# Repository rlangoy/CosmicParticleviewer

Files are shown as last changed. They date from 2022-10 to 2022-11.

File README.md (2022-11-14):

# Cosmic particle readout system overview
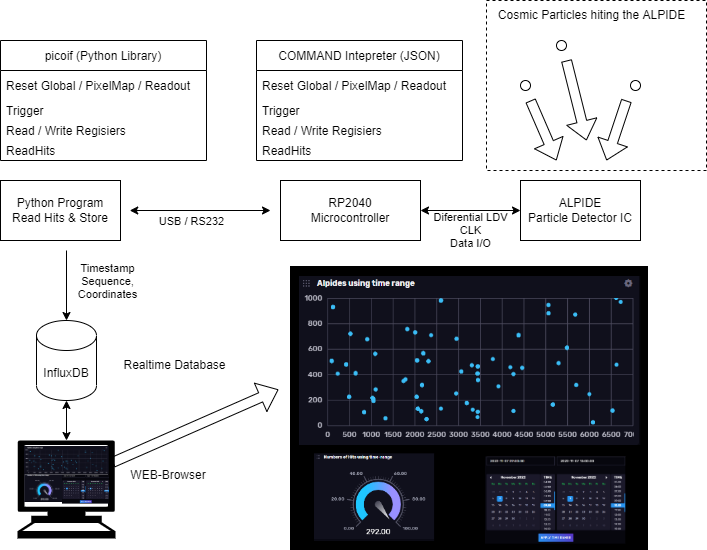
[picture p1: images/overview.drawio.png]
 
 
## Readout Hardware
 
 
Schematics and PCB layout is found inn the kicadv6 folder   \
Design files for the cover is found in the the CAD foldder 

## Project Content 
### alpideInterface
Microcontroller firmware source for [Arduino IDE 2.x](https://github.com/arduino/arduino-ide) \
&nbsp; parses JSON command and sends it to the ALPIDES \
&nbsp; More Info Available in the [README](/ArduinoV2/README.md) 

### KicadV6  
PCB Design files for [Kicadv6] (https://www.kicad.org/) \
&nbsp; More Info Available in the [README](/KicadV6/README.md) 

### CAD  
CAD Design files for PCB cover [Freecad v0.21] (https://www.freecad.org/) \
&nbsp; More Info Available in the [README](/CAD/README.md) 

### Python
Python ver 3.x Library and Examples for reading/accessing the Alpide OB Modules \
&nbsp; More Info Available in the [README](/Python/README.md)

### InfluxDB
InfluxDB 2.x Python3 script for inserting ALPIDE data into the daatabase and Script for building the Dashboard \
&nbsp; More Info Available in the [README](/InfluxDB/README.md)

## Getting started
- Transfer .u2f file to the RPI Pico
- Modify Serial port in plotAplideHitmap.py
  - Run [plotAplideHitmap.py](/Python/plotAplideHitmap.py) (python3 plotAplideHitmap.py )

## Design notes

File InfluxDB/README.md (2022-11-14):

## Usage
This folder contains the files needed to insert data into InfluxDB .

## InfluxDB Installation
Complete install instructions is available from the influxdata  [install page](https://docs.influxdata.com/influxdb/v2.5/install/) \
Lastest software could be downloaded from the influxdata's github [release page ](https://github.com/influxdata/influxdb/releases) 

## Insert APIDE Data into the page.
Edit the file insertToDb.py and replase token/org/bucket and update the serialPort
```
token = "Ok7Hy44aCG_1DJGyo0DciVqX3psxGnEDM8FUMVoxS6BPo7zKF82VVQFgQTSP5prj-jfvCvDfNClQhMDMQCRRgw=="
org = "USN"
bucket = "AlpideData"   #"AlpideData"

serialPort='/dev/ttyACM0'  #'COM95
```

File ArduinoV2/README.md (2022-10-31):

## Usage
This folder contains the files nessesary to grenerate the microcontroller firmware \
More info on the firmware is available in the [/ArduinoV2/alpideInterface/README](/ArduinoV2/alpideInterface/README.md) 

## Installation

The microcontroller firmware could be buildt using Command-Line tools (Arduino CLI) or the Arduino IDE 

### Installl Arduino CLI Linux

The Arduino CLI is used to compile and program the device from the command-line \
To program the device enter the folowing :

```
wget -qO arduino-cli.tar.gz https://downloads.arduino.cc/arduino-cli/arduino-cli_latest_Linux_64bit.tar.gz
sudo tar xf arduino-cli.tar.gz -C /usr/local/bin arduino-cli
rm -rf arduino-cli.tar.gz
arduino-cli lib install ArduinoJson
 
arduino-cli config init --additional-urls https://github.com/earlephilhower/arduino-pico/releases/download/global/package_rp2040_index.json
arduino-cli core install rp2040:rp2040

arduino-cli core update-index
arduino-cli compile --fqbn rp2040:rp2040:rpipico  alpideInterface 
arduino-cli  upload --fqbn rp2040:rp2040:rpipico  alpideInterface -p /dev/ttyACM0
```

### Install Arduino IDE 2.x
Download and install  [Arduino IDE 2.x](https://github.com/arduino/arduino-ide)
In Arduino IDE 2.x \ 
-  Install the compiler Raspberry Pi Pico/RP2040 by Eale F. Phillower v 2.5.x \
      Inside The Arduino IDE select: \
         File | Preferences.. | Aditional Board Managers \
        add the URL: https://github.com/earlephilhower/arduino-pico/releases/download/global/package_rp2040_index.json

- Installation Library ArduinoJson
     Complete install instructions could be found [here](https://arduinojson.org/v6/doc/installation/) \
     Short Install instructions: \
       Open the Arduino Library Manager  [Ctrl] + [Shift] + I \
       Search for “ArduinoJson” \
       Select the version: 6.19.4   \
       Click install. 

Compile and Upload the code

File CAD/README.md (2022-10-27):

# Freecad v0.21 Files for circuitboard protector for Raspberry Pico (RP2040) interface to Outer Barrel Module

Circuit Protector :) \
Designed for FDM printing

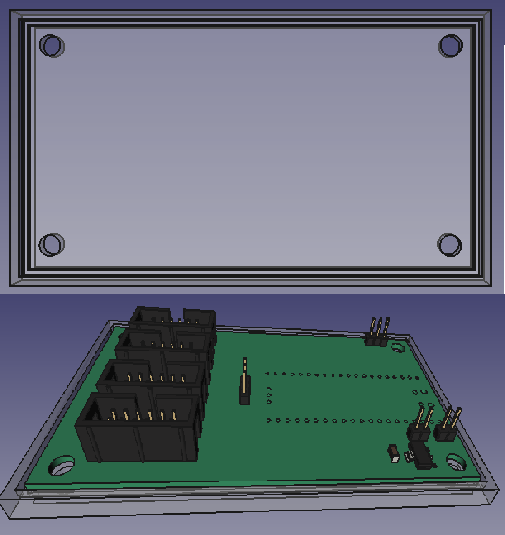
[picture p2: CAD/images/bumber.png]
Bumper PCB Layout
 
\

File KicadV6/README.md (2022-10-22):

# Kicad Files for Raspberry Pico (RP2040) interface to Outer Barrel Module
## PCB Layout. 
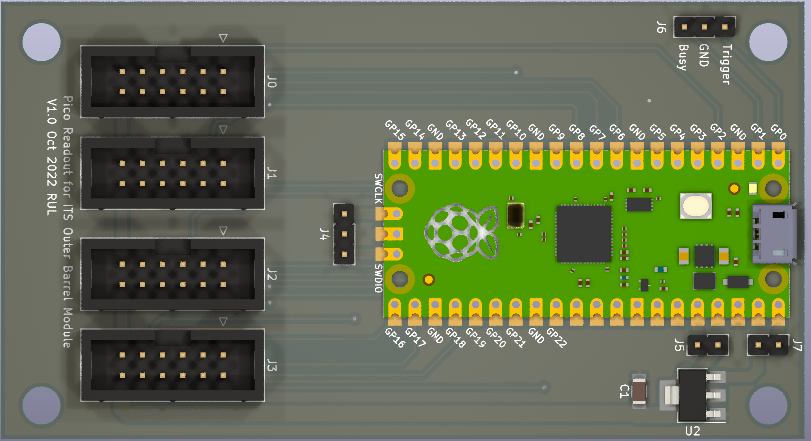
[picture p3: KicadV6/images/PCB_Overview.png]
PCB Layout
 
\
The Mounting holes is designed for 4M Screws \

## RP2040 Pinout 
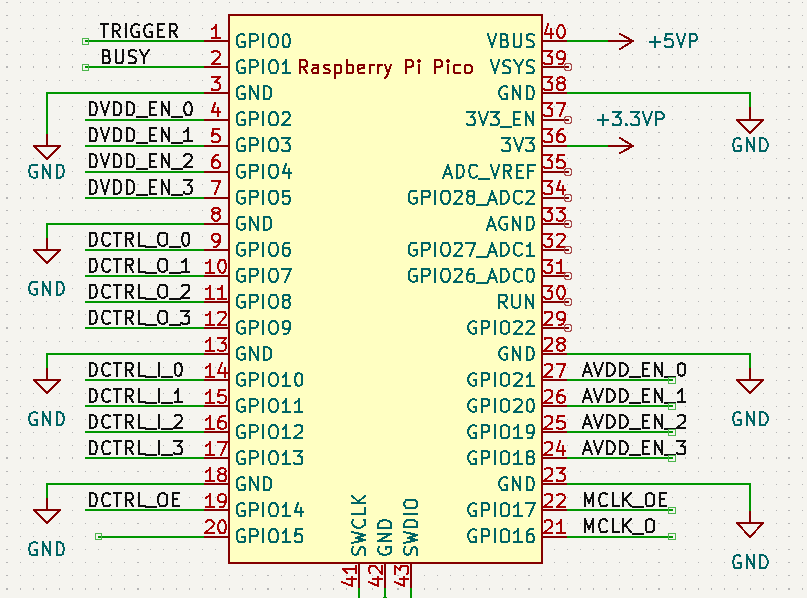
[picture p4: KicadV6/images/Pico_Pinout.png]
PCB Layout Pico Pinout

## +3,3V Source Selection
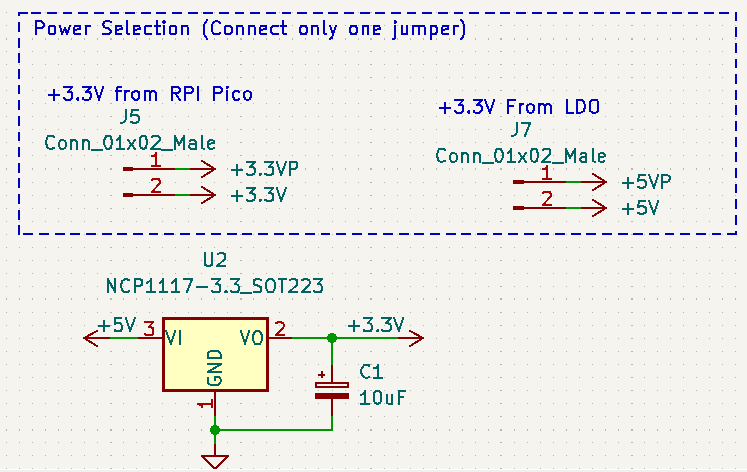
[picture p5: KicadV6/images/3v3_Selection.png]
PCB Layout +3.3V Souce Selection


## Fabrication
The PCB can be fabricated by uploading the gerber files (KicadV6\gerber\Pico_Interface.zip)  to a [PCB manufacurer](https://jlcpcb.com/) 

## Bil of Materials (BOM)

| Quantity | Reference(s) | Prod no | Farnell order no | Description | |
|---|---|---|---|---|---|
| 1 | C1 | T491A106K016AT | 1457414 | T491A106K016AT CAP, 10µF, 16V, 10%, 1206, SMD | |
| 4 | J0-J3 | MC-254-12-00-ST-DIP | 2843528 | MC-254-12-00-ST-DIP CONNECTOR, HEADER, 12POS, 2ROW, 2.54MM | |
| 1 | U2 | NCP1117ST33T3G | 1652366 | NCP1117ST33T3G IC, LINEAR VOLTAGE REGULATOR | |
| 1 | U1 | | | Rasbperry Pi Pico | |

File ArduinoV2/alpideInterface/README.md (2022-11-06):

# Arduino Pico Readout Firmware

The Files ALPIDE.h & ALPIDE.cpp is removed due to properitary transfer protocol...

The Firmware is buildt for Arduino IDE 2.0 
   -  Code not specific for any hardware, but tested on RPI Pico (RP2040)
   -  Designed for the PCB board "Raspberry Pico (RP2040) interface to Outer Barrel Module"
   -  JSON for intepreting commands the reply might not be formed as JSON due to performance

## Commands:
JSON input
   - single   reg read 
     - {"readRegister": {     "chipID": 112,     "addr": 1545   } }
     - Returns values as {"reg" : xxx ,  "chipID":xxx , "addr":xxx, "value"}
   - multiple reg read  
     - {"readRegister": [{"chipID": 112,     "addr": 1545},{"chipID": 113,     "addr": 1545}]    }
     - Returns values as {"reg" : xxx ,  "chipID":xxx , "addr":xxx, "value"}
 
   - single   reg write 
     - {"writeRegister": {     "chipID": 112,   "addr": 1545  ,"data" : 100  } }
     - Returns values as "ok"
   - multiple reg write  
     - {"writeRegister": [{"chipID": 112, "addr": 1545 ,"data" : 100},{"chipID": 113, "addr": 1545 ,"data" : 101}]    }
     - Returns values as "ok"

   -  sendRest  - Sends reset signal
      - {"sendRest": "True" }
      - Returns values as "ok"

   -  sendTrigger  - Sends trigger signal (6000clk's)
      - {"sendTrigger": "True" }
      - Returns values as "ok"

   - getPixelFrameData  - Return events/pixel-hit data 
      - format : streamRaw: Dumps raw data 
      - {"getPixelFrameData": ["chipID" , 112 ] }
      - Return stream of 24 bit binary data \
&nbsp;  Format: \
&nbsp;&nbsp;&nbsp;&nbsp; 0xA093FF - starting with header    \
&nbsp;&nbsp;&nbsp;&nbsp; 0xB0FFFF - end with trailer         \
\
&nbsp;&nbsp;&nbsp;&nbsp; 0xFFFFFF - If not ready

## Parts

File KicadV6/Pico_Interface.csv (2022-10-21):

Source: | C:\Users\runel\Documents\Skole\CERN\arduinopicoalpidereadout\KicadV6\Pico_Interface.kicad_sch
Date: | Fri Oct 21 16:37:29 2022
Tool: | Eeschema (6.0.8)
Generator: | C:\Program Files\KiCad\6.0\bin\scripting\plugins/bom_csv_grouped_by_value.py
Component Count: | 11
Individual Components:
Item | Qty | Reference(s) | Value | LibPart | Footprint | Datasheet | Farnell URL
 |  | C1 | 10uF | Device:C_Polarized_Small | Capacitor_SMD:C_1206_3216Metric_Pad1.33x1.80mm_HandSolder | https://4donline.ihs.com/images/VipMasterIC/IC/KEME/KEME-S-A0006487387/KEME-S-A0006487387-1.pdf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 | https://no.farnell.com/kemet/t491a106k016at/cap-10-f-16v-10-1206-smd/dp/1457414
 |  | J0 | Conn_02x06_Odd_Even | Connector_Generic:Conn_02x06_Odd_Even | Connector_IDC:IDC-Header_2x06_P2.54mm_Vertical | https://no.farnell.com/multicomp/mc-254-12-00-st-dip/connector-header-12pos-2row-2/dp/2843528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 | https://no.farnell.com/multicomp/mc-254-12-00-st-dip/connector-header-12pos-2row-2/dp/2843528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
 |  | J1 | Conn_02x06_Odd_Even | Connector_Generic:Conn_02x06_Odd_Even | Connector_IDC:IDC-Header_2x06_P2.54mm_Vertical | https://no.farnell.com/multicomp/mc-254-12-00-st-dip/connector-header-12pos-2row-2/dp/2843528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 | https://no.farnell.com/multicomp/mc-254-12-00-st-dip/connector-header-12pos-2row-2/dp/2843528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
 |  | J2 | Conn_02x06_Odd_Even | Connector_Generic:Conn_02x06_Odd_Even | Connector_IDC:IDC-Header_2x06_P2.54mm_Vertical | https://no.farnell.com/multicomp/mc-254-12-00-st-dip/connector-header-12pos-2row-2/dp/2843528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 | https://no.farnell.com/multicomp/mc-254-12-00-st-dip/connector-header-12pos-2row-2/dp/2843528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
 |  | J3 | Conn_02x06_Odd_Even | Connector_Generic:Conn_02x06_Odd_Even | Connector_IDC:IDC-Header_2x06_P2.54mm_Vertical | https://no.farnell.com/multicomp/mc-254-12-00-st-dip/connector-header-12pos-2row-2/dp/2843528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 | https://no.farnell.com/multicomp/mc-254-12-00-st-dip/connector-header-12pos-2row-2/dp/2843528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
 |  | J4 | Conn_01x03_Male | Connector:Conn_01x03_Male | Connector_PinHeader_2.54mm:PinHeader_1x03_P2.54mm_Vertical | ~
 |  | J5 | Conn_01x02_Male | Connector:Conn_01x02_Male | Connector_PinHeader_2.54mm:PinHeader_1x02_P2.54mm_Vertical | ~
 |  | J6 | Conn_01x03_Male | Connector:Conn_01x03_Male | Connector_PinHeader_2.54mm:PinHeader_1x03_P2.54mm_Vertical | ~
 |  | J7 | Conn_01x02_Male | Connector:Conn_01x02_Male | Connector_PinHeader_2.54mm:PinHeader_1x02_P2.54mm_Vertical | ~
 |  | U1 | Pico | MCU_RaspberryPi_and_Boards:Pico | RPi_Pico:RPi_Pico_SMD_TH | https://www.farnell.com/datasheets/3189214.pdf | https://no.farnell.com/raspberry-pi/raspberry-pi-pico/raspberry-pi-32bit-arm-cortex/dp/3643332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
 |  | U2 | NCP1117-3.3_SOT223 | Regulator_Linear:NCP1117-3.3_SOT223 | Package_TO_SOT_SMD:SOT-223-3_TabPin2 | http://www.onsemi.com/pub_link/Collateral/NCP1117-D.PDF | https://no.farnell.com/on-semiconductor/ncp1117st33t3g/ic-linear-voltage-regulator/dp/1652366
Collated Components:
Item | Qty | Reference(s) | Value | LibPart | Footprint | Datasheet | Farnell URL
1 | 1 | C1 | 10uF | Device:C_Polarized_Small | Capacitor_SMD:C_1206_3216Metric_Pad1.33x1.80mm_HandSolder | https://4donline.ihs.com/images/VipMasterIC/IC/KEME/KEME-S-A0006487387/KEME-S-A0006487387-1.pdf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 | https://no.farnell.com/kemet/t491a106k016at/cap-10-f-16v-10-1206-smd/dp/1457414
2 | 4 | J0, J1, J2, J3 | Conn_02x06_Odd_Even | Connector_Generic:Conn_02x06_Odd_Even | Connector_IDC:IDC-Header_2x06_P2.54mm_Vertical | https://no.farnell.com/multicomp/mc-254-12-00-st-dip/connector-header-12pos-2row-2/dp/2843528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 | https://no.farnell.com/multicomp/mc-254-12-00-st-dip/connector-header-12pos-2row-2/dp/2843528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
3 | 2 | J4, J6 | Conn_01x03_Male | Connector:Conn_01x03_Male | Connector_PinHeader_2.54mm:PinHeader_1x03_P2.54mm_Vertical | ~
4 | 2 | J5, J7 | Conn_01x02_Male | Connector:Conn_01x02_Male | Connector_PinHeader_2.54mm:PinHeader_1x02_P2.54mm_Vertical | ~
5 | 1 | U1 | Pico | MCU_RaspberryPi_and_Boards:Pico | RPi_Pico:RPi_Pico_SMD_TH | https://www.farnell.com/datasheets/3189214.pdf | https://no.farnell.com/raspberry-pi/raspberry-pi-pico/raspberry-pi-32bit-arm-cortex/dp/3643332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
6 | 1 | U2 | NCP1117-3.3_SOT223 | Regulator_Linear:NCP1117-3.3_SOT223 | Package_TO_SOT_SMD:SOT-223-3_TabPin2 | http://www.onsemi.com/pub_link/Collateral/NCP1117-D.PDF | https://no.farnell.com/on-semiconductor/ncp1117st33t3g/ic-linear-voltage-regulator/dp/1652366

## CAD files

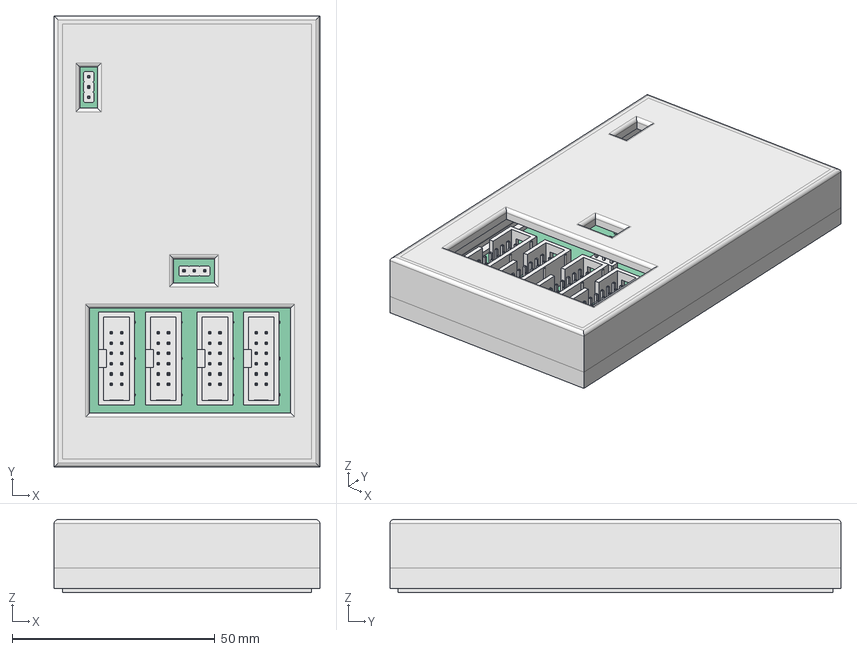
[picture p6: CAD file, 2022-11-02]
CAD/AlpideReaderCover.FCStd
65.5 x 111.1 x 18.0 mm
Pcb_896a
J7_PinHeader_1x02_P254mm_Vertical_c1ae9f7b4cb4 x 2
J1_IDC_Header_2x06_P254mm_Vertical_2bd6d999c536 x 4
U2_SOT_223_b2f08355be2d
J6_PinHeader_1x03_P254mm_Vertical_7fd6783959d2 x 2
C1_C_1206_3216Metric_84f38c0c58ee

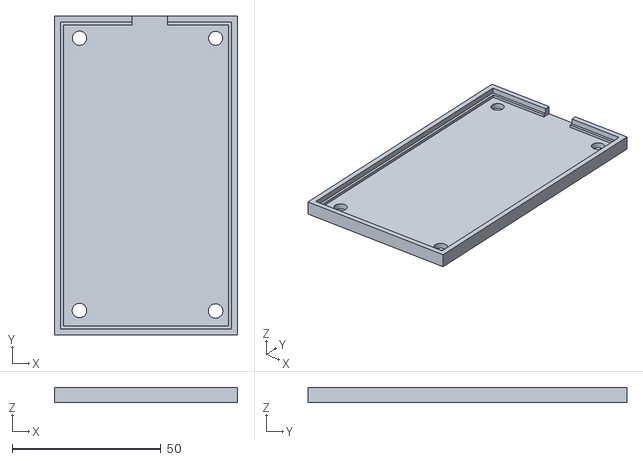
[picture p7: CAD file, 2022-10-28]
CAD/Pico_Interface1-Body.stl
61.5 x 107.1 x 5.00

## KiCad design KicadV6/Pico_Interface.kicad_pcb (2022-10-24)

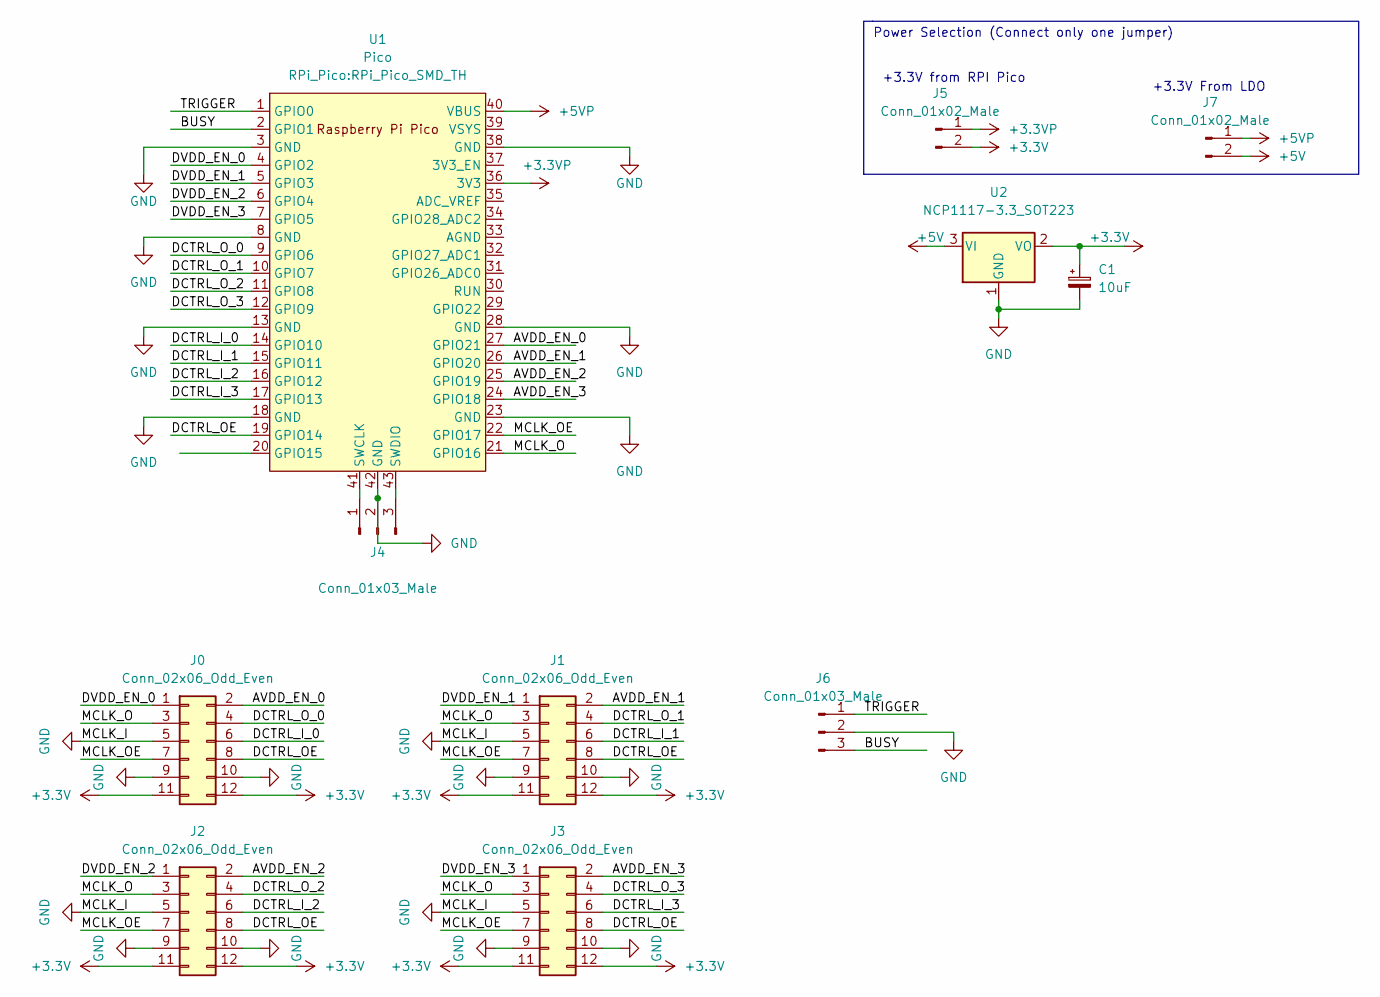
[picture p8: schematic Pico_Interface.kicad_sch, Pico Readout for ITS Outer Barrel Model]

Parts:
C1: 10uF; C_1206_3216Metric_Pad1.33x1.80mm_HandSolder
J0, J1, J2, J3: Conn_02x06_Odd_Even; IDC-Header_2x06_P2.54mm_Vertical
J4, J6: Conn_01x03_Male; PinHeader_1x03_P2.54mm_Vertical
J5, J7: Conn_01x02_Male; PinHeader_1x02_P2.54mm_Vertical
U1: Pico; RPi_Pico_SMD_TH
U2: NCP1117-3.3_SOT223; SOT-223-3_TabPin2

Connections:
+3.3V: C1.1, J0.11, J0.12, J1.11, J1.12, J2.11, J2.12, J3.11, J3.12, J5.2, U2.2 (VO)
+3.3VP: J5.1, U1.36 (3V3)
+5V: J7.2, U2.3 (VI)
+5VP: J7.1, U1.40 (VBUS)
/AVDD_EN_0: J0.2, U1.27 (GPIO21)
/AVDD_EN_1: J1.2, U1.26 (GPIO20)
/AVDD_EN_2: J2.2, U1.25 (GPIO19)
/AVDD_EN_3: J3.2, U1.24 (GPIO18)
/BUSY: J6.3, U1.2 (GPIO1)
/DCTRL_I_0: J0.6, U1.14 (GPIO10)
/DCTRL_I_1: J1.6, U1.15 (GPIO11)
/DCTRL_I_2: J2.6, U1.16 (GPIO12)
/DCTRL_I_3: J3.6, U1.17 (GPIO13)
/DCTRL_OE: J0.8, J1.8, J2.8, J3.8, U1.19 (GPIO14)
/DCTRL_O_0: J0.4, U1.9 (GPIO6)
/DCTRL_O_1: J1.4, U1.10 (GPIO7)
/DCTRL_O_2: J2.4, U1.11 (GPIO8)
/DCTRL_O_3: J3.4, U1.12 (GPIO9)
/DVDD_EN_0: J0.1, U1.4 (GPIO2)
/DVDD_EN_1: J1.1, U1.5 (GPIO3)
/DVDD_EN_2: J2.1, U1.6 (GPIO4)
/DVDD_EN_3: J3.1, U1.7 (GPIO5)
/MCLK_O: J0.3, J1.3, J2.3, J3.3, U1.21 (GPIO16)
/MCLK_OE: J0.7, J1.7, J2.7, J3.7, U1.22 (GPIO17)
/TRIGGER: J6.1, U1.1 (GPIO0)
GND: C1.2, J0.5, J0.9, J0.10, J1.5, J1.9, J1.10, J2.5, J2.9, J2.10, J3.5, J3.9, J3.10, J4.2, J6.2, U1.3 (GND), U1.8 (GND), U1.13 (GND), U1.18 (GND), U1.23 (GND), U1.28 (GND), U1.38 (GND), U1.42 (GND), U2.1 (GND)
unnamed: J4.1, U1.41 (SWCLK)
unnamed: J4.3, U1.43 (SWDIO)

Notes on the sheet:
Power Selection (Connect only one jumper)
+3.3V From LDO
+3.3V from RPI Pico

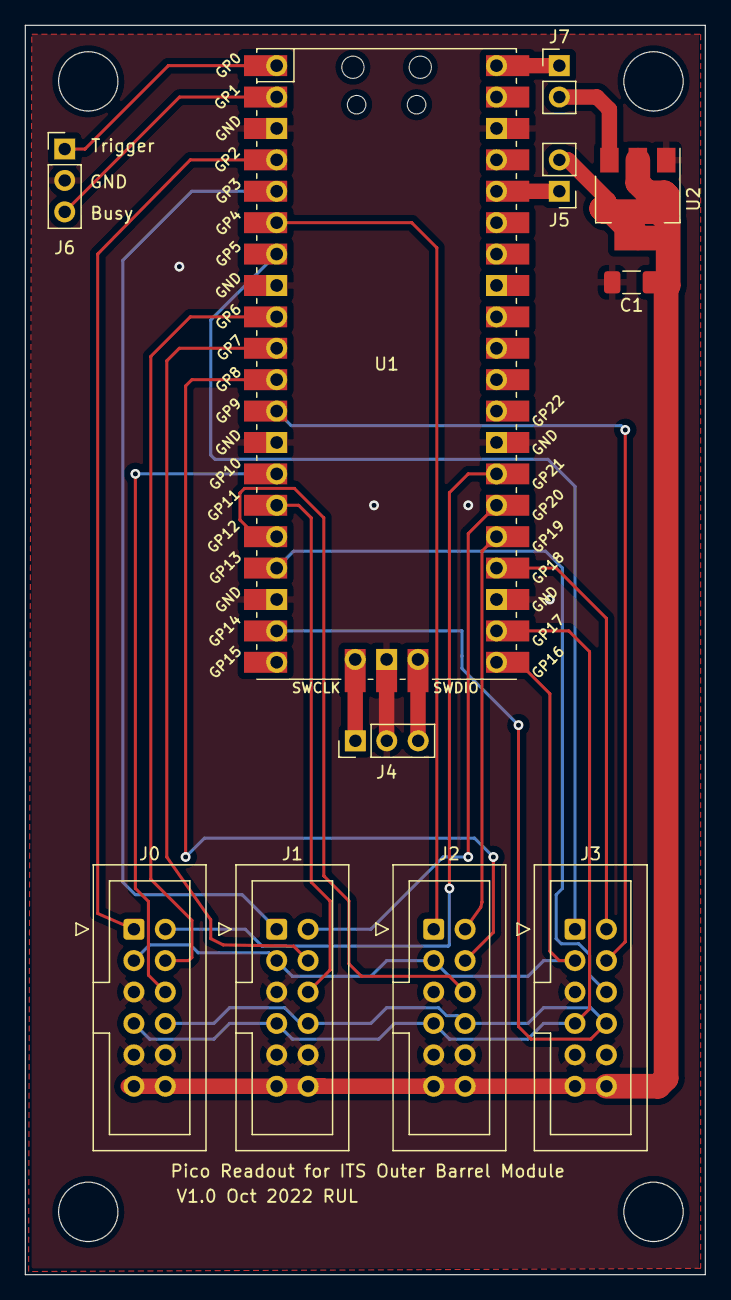
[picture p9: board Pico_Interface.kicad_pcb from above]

Board: 2 copper layers, 55.0 x 101.1 mm, 11 parts (0 on the bottom side), 28 nets.

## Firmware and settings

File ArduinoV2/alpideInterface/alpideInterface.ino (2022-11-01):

#include <ArduinoJson.h>
#include <ArduinoJson.hpp>

/******************************************************************
 *   Install Raspberry Pi Pico/RP2040 by Eale F. Phillower v 2.5.x
 *     File | Preferences.. | Aditional Board Managers
 *   https://github.com/earlephilhower/arduino-pico/releases/download/global/package_rp2040_index.json
 *
 *  Install arduinojson
 *   Install instructions : https://arduinojson.org/v6/doc/installation/
 *     Open the Arduino Library Manager  [Ctrl] + [Shift] + I
 *      Search for “ArduinoJson”
 *      Select the version: 6.19.4 
 *      Click install.
 *************************************************************/
#include "ALPIDE.h"

ALPIDE alpide;

//#undef  UseSerialUSB         // Send messages on USART0 (GPIO port 0,1 ) (for picoprobe output...)
#define UseSerialUSB      // Unmment to send messages on the USB<->RS232


#ifdef UseSerialUSB
  HardwareSerial &SerialInUse = Serial;
#else
  HardwareSerial &SerialInUse = Serial1;
#endif

/*   
*  Test function for checking alpide.readRegister / alpide.writeRegister
*  Checks that the Alpides is responding
*/
void regReadWriteTest()
{
  int cnt=0;
  int errorCnt=0;
  SerialInUse.println("Register R/W - Test on ALIDEs width id 0x70->0x76 & 0x78->0x7E");
  SerialInUse.println("  Writes ALPIDE_REG_VTEMP Reg values from 0x0 to 0xD");
  for(int ii=0x0;ii<=8;ii+=8)
    for(int id=0x70+ii;id<0x70+7+ii;id++)
      alpide.writeRegister(id, ALPIDE_REG_VTEMP, cnt++);
  
  //Read back
  SerialInUse.println("  Reads back ALPIDE_REG_VTEMP Reg values  0x0 to 0xD");
  cnt=0;
  for(int ii=0x0;ii<=8;ii+=8)
  {
    for(int id=0x70+ii;id<0x70+7+ii;id++)
    {   
        int32_t regVal=alpide.readRegister(id, ALPIDE_REG_VTEMP);
        if(regVal!=cnt)
        { errorCnt++;
          SerialInUse.println("  --== Error ==--");
          SerialInUse.print("  Chip ID : 0x");
          SerialInUse.print(id,HEX);
          SerialInUse.print("  Register ALPIDE_REG_VTEMP  Value ");
          SerialInUse.print(": 0x");
          SerialInUse.println(regVal,HEX);

          SerialInUse.print("  Expected value: 0x");
          SerialInUse.print(cnt,HEX);
          SerialInUse.print(" But read : 0x") ;
          SerialInUse.println(regVal,HEX);        
        }
        cnt++;
    }
  }

  if(errorCnt)
  {
    SerialInUse.println("  --------------------------------------");
    SerialInUse.println("  | Warning Regsiter Read/Write Error  |");
    SerialInUse.print  ("  |  ");
    SerialInUse.print(errorCnt);
    SerialInUse.println("   errors found !!!               |");
    SerialInUse.println("  --------------------------------------");
    SerialInUse.println();
  }  
  else
  {
    SerialInUse.println("  Sucessfully verifyed register contents");
    SerialInUse.println();
  }

}

bool bDoOnce=true;
void setup() {

  SerialInUse.begin(115200);   //Set baudrate

  //SerialInUse.println("\r\n--== Init Alpide ==-- ");
  alpide.init();

  //regReadWriteTest();   // Test reg read / Write 
  
  //Disable pix-on chip..
  // alpide.maskAllPixels(0x70,true);  
  alpide.sendTrigger();
  delay(1);   //Wait a bit after sending trigger ???
 // alpide.sendTrigger();

 
}



#define BUFF_SIZE 100

/*  parseReadRegister - checks is JSON root-key is "readRegister"
 *   
 *  Executes ALPIDE read of register using chipID and address
 *  JSON Example input
 *       single   reg read   {"readRegister": {     "chipID": 112,     "addr": 1545   } }
 *       multiple reg read   {"readRegister": [{"chipID": 112,     "addr": 1545},{"chipID": 113,     "addr": 1545}]    }
 **
 *  Output Returns values as {"reg" : xxx ,  "chipID":xxx , "addr":xxx,"value"}
 *'
*/
void parseReadRegister(StaticJsonDocument<2000> doc,bool debug=false)
{
   //Check if readRegister exisists
   if(doc.containsKey("readRegister"))   //Command readRegister
    {
      JsonArray array = doc["readRegister"].as<JsonArray>();
      
      if(array.isNull())
      {   // read single register
          uint8_t chipID =doc["readRegister"]["chipID"].as<int>();
          uint16_t  addr =doc["readRegister"]["addr"].as<int>();
          int32_t  regVal=alpide.readRegister(chipID, addr);
          char strStrReply[80];
          sprintf(strStrReply,"{ \"alpideRegister\": [ { \"addr\": %d , \"data\": %d}  ] }",addr,regVal);
          SerialInUse.println(strStrReply);

          
          if(debug)
          {  
            SerialInUse.print("cmd - readRegister(");
            SerialInUse.print(" chipID 0x");
            SerialInUse.print(chipID,HEX);
            SerialInUse.print(",addr 0x");
            SerialInUse.print(addr,HEX); 
            SerialInUse.println(")");            
          }
          

      }else
      { // read multiple registers
        int cnt=doc["readRegister"].size();
        for(int idx=0;idx<cnt;idx++)
        {
          uint8_t chipID =doc["readRegister"][idx]["chipID"].as<int>();
          uint16_t  addr =doc["readRegister"][idx]["addr"].as<int>();
          
          int32_t  regVal=alpide.readRegister(chipID, addr);
          char strStrReply[80];
          sprintf(strStrReply,"{ \"alpideRegister\": [ { \"addr\": %d , \" value\": %d}  ] }",addr,regVal);
          SerialInUse.println(strStrReply);

          if(debug)
          {
            SerialInUse.print("cmd - readRegister(");
            SerialInUse.print(" chipID 0x");
            SerialInUse.print(chipID,HEX);
            SerialInUse.print(",addr 0x");
            SerialInUse.print(addr,HEX); 
            SerialInUse.println(")");
          }
        }
      }
    }
}



/*   parseMaskPixels
 *  JSON Example input
 *       single   pixel mask   {"maskPixels":  {"chipID": 112, "x": 100 ,"y" : 200  } }
 *       multiple pixel mask   {"maskPixels": [{"chipID": 112, "x": 100 ,"y" : 200  },{"chipID": 112, "x": 101 ,"y" : 201  }]    }
 */
void parseMaskPixels(StaticJsonDocument<2000> doc)
{
 //Check if writeRegister exisists
   if(doc.containsKey("maskPixels"))   //Command writeRegister
    {
      JsonArray array = doc["maskPixels"].as<JsonArray>();
      
      if(array.isNull())
      {   // read single register
          uint8_t chipID =doc["maskPixels"]["chipID"].as<int>();
          uint16_t  x =doc["maskPixels"]["x"].as<int>();
          int16_t   y =doc["maskPixels"]["dyata"].as<int>();
          
          alpide.addMaskPixel(chipID, x,y);
          
          SerialInUse.println("ok");          
      }else
      { // read multiple registers
        int cnt=doc["maskPixels"].size();
        for(int idx=0;idx<cnt;idx++)
        {
          uint8_t chipID =doc["maskPixels"][idx]["chipID"].as<int>();
          uint16_t  x =doc["maskPixels"][idx]["x"].as<int>();
          uint16_t  y =doc["maskPixels"][idx]["y"].as<int>();

          alpide.addMaskPixel(chipID, x,y);          
        }
        SerialInUse.println("ok");          
      }
    } 
}

/*  parseWriteRegister - checks is JSON root-key is "readRegister"
 *   
 *  Executes ALPIDE read of register using chipID and address
 *  JSON Example input
 *       single   reg read   {"writeRegister": {     "chipID": 112,   "addr": 1545  ,"data" : 100  } }
 *       multiple reg read   {"writeRegister": [{"chipID": 112, "addr": 1545 ,"data" : 100},{"chipID": 113, "addr": 1545 ,"data" : 101}]    }
 **
 *
*/
void parseWriteRegister(StaticJsonDocument<2000> doc)
{
   //Check if writeRegister exisists
   if(doc.containsKey("writeRegister"))   //Command writeRegister
    {
      JsonArray array = doc["writeRegister"].as<JsonArray>();
      
      if(array.isNull())
      {   // read single register
          uint8_t chipID =doc["writeRegister"]["chipID"].as<int>();
          uint16_t  addr =doc["writeRegister"]["addr"].as<int>();
          int16_t   data =doc["writeRegister"]["data"].as<int>();
          
          int  ret=alpide.writeRegister(chipID, addr,data);
          SerialInUse.println("ok");          
      }else
      { // read multiple registers
        int cnt=doc["writeRegister"].size();
        for(int idx=0;idx<cnt;idx++)
        {
          uint8_t chipID =doc["writeRegister"][idx]["chipID"].as<int>();
          uint16_t  addr =doc["writeRegister"][idx]["addr"].as<int>();
          int16_t   data =doc["writeRegister"][idx]["data"].as<int>();
       
          int  ret=alpide.writeRegister(chipID, addr,data);          
        }
        SerialInUse.println("ok");          
      }
    }
}


/*  parseGetPixelFrameData  - Return events/pixel-hit data 
 *   
 *  format : streamRaw: Dumps raw data 
 *
 *   usage:
 *      {"getPixelFrameData": ["chipID" , 112 ] }
 *      {"getPixelFrameData": "debugData" }  - Returns debug data
 *    Param:
 *           ReturnRawData  <-  Returns binary 24 bits data 
 *                                    starting with header   0xA093FF
 *                                    end with trailer       0xB0FFFF
 *                               If not ready                0xFFFFFF
 */
void parseGetPixelFrameData(StaticJsonDocument<2000> doc,bool debug=false)
{
    if(doc.containsKey("getPixelFrameData")) 
    {
       //  IDEA...  ["getPixelFrameData"]== "returnRawData")
      JsonArray array = doc["getPixelFrameData"].as<JsonArray>();
       if(array.isNull())
       {  //chipID - is missing ... 
          if (doc["getPixelFrameData"]=="debugData")
          { //Send debug data...
            //                     Header           Region-id         data - short     data - long         trailer
            //                    #0xA093FF          #0xC0FFF           0x42BDFF        #0x030128          0xB0FFFF
            char outPixelData[]={0xA0,0x93,0xFF,   0xC0,0xFF,0xFF,   0x42,0xBD, 0xFF,  0x03,0x01,0x28,    0xB0,0xFF,0xFF };
            SerialInUse.write(outPixelData, sizeof(outPixelData));
          }
        }
       else
       {      
         int cnt=doc["getPixelFrameData"].size();
         for(int idx=0;idx<cnt;idx++)
            {
                uint8_t chipID =doc["getPixelFrameData"][idx]["chipID"].as<int>();
                alpide.dumpEventWords24Bit(SerialInUse,chipID,63000);
            }          

          
       }

     //To be implemented...
     //alpide.dumpEventWords24Bit(0x70,25000);
    }
}


void parseSendReset(StaticJsonDocument<2000> doc,bool debug=false)
{
    if(doc.containsKey("sendRest")) 
    {
          alpide.sendReset();
          SerialInUse.println("ok");
          SerialInUse.flush();    
    }
}


void parseSendTrigger(StaticJsonDocument<2000> doc,bool debug=false)
{
    if(doc.containsKey("sendTrigger")) 
    {
          alpide.sendTrigger();
          SerialInUse.println("ok");
          SerialInUse.flush();    
    }
}


void readJson()
{
    StaticJsonDocument<2000> doc;
    while (SerialInUse.available() == 0) {}     //wait for data available

    String teststr = Serial.readString();
    //Serial.print(teststr);
 
    DeserializationError err = deserializeJson(doc, teststr);

    if (err == DeserializationError::Ok) 
    {
      parseReadRegister(doc);
      parseWriteRegister(doc);

      parseSendReset(doc);
      parseSendTrigger(doc);

      parseGetPixelFrameData(doc);
      parseMaskPixels(doc);

      doc.clear();  //Empty doc (rdy for next commands..)
    } 
    else 
    {
      // Print error to the "debug" serial port
      SerialInUse.print("deserializeJson() returned ");
      SerialInUse.println(err.c_str());

      // Flush all bytes in the "link" serial port buffer
      while (Serial1.available() > 0)
        SerialInUse.read();
    }
}



/* Make things happening :) */
void loop() {


  //regReadWriteTest();
  readJson();
  //delay(3000);

  //alpide.dumpEventWordsPy(SerialInUse,0x70,25000);
  //uint16_t x[100];
  //uint16_t y[100];

 // uint32_t buff[BUFF_SIZE];
    //delay(3000);
  
  // alpide.broadcastCommand(0x55) // Send trigger  TRIGGER 
                                   // Strobe lasts for 6000 clks (def i alpide init.. (ALPIDE_REG_FROMU_CFG2))

  // alpide.sendTrigger();
   //readJson();

  //int nHits=alpide.readEvent(0x78,x,y,100);
  // alpide.sendTrigger();
  //delay(1000);
   //if(bDoOnce)
   // alpide.sendTrigger();
  /* {
     bDoOnce=false;
      //alpide.sendTrigger();
      int id=0x70;
      for(int ii=0x0;ii<=8;ii+=8)
      {
        for(int id=0x70+ii;id<0x70+7+ii;id++)
        {
          
          // Debug get data to decode using python
          //alpide.dumpEventWordsPy(0x70,25000);
          
          
          uint16_t x[100];
          uint16_t y[100];
          SerialInUse.print(",");
          SerialInUse.print(alpide.readPixel(0x70,x,y,1000));
          */
          //alpide.readPixel(0x70,x,y,1000);
          
/*
          int nhits=alpide.readEvent(0x70,x,y,1000);
          if( nhits>0) 
          {         
            Serial1.println(nhits);
            Serial1.println(nhits);
          }
          */


           /*
          //int nHits=alpide.readEvent(id,x,y,100);

          int buf_cnt=alpide.readEventWords(id,buff,BUFF_SIZE);
          //if(nHits>=0)
          {
            SerialInUse.print("Chip ID 0x");
            SerialInUse.print(id,HEX);                        

            SerialInUse.print(" buff[0] : ");
            SerialInUse.print(buff[0],HEX);  

            SerialInUse.print(" Data-Type : ");
            uint16_t x,y;
            int retDecodeWord=alpide.decodeEventWord(buff[0],&x,&y);
            if(retDecodeWord<0)
              SerialInUse.print(retDecodeWord);
            else
               {
                  SerialInUse.print( " X : 0x");
                  SerialInUse.print( x, HEX);
                  SerialInUse.print( " Y : 0x");
                  SerialInUse.print( y, HEX);
               }

            SerialInUse.print(" buf_cnt : ");
            SerialInUse.println(buf_cnt);
          }

          */

          /*  Debug...
          int32_t lo=alpide.readRegister(id,ALPIDE_REG_DMU_FIFO_LO);  //Wait 20-30 sec for events...
          int32_t hi=alpide.readRegister(id,ALPIDE_REG_DMU_FIFO_HI);

          if (!((lo==0xFFFF) & (hi=0xFFFF)))
          {
            SerialInUse.print("Chip ID 0x");
            SerialInUse.print(id,HEX);
            
            SerialInUse.print("  Register ALPIDE_REG_DMU_FIFO_LO  Value ");
            SerialInUse.print(": 0x");
            SerialInUse.print(lo,HEX);
            
            SerialInUse.print("  Fifi High : 0x");
            SerialInUse.println(hi,HEX);
          }
          else
            SerialInUse.println("-");
            */
/*
        }
      }
   }
*/
//  SerialInUse.print("\r\nHits : ");
 // SerialInUse.println(nHits);
 //delay(1000);
}

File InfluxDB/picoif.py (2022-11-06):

# #!/usr/bin/env python3
# 
# import alpideseq
from time import sleep
import matplotlib.pyplot as plt
import serial
import serial.tools.list_ports
import numpy as np
import json

class OuterBarriel():
    
        # constructor
    def __init__(self,serialPortName):
     
        comlist = serial.tools.list_ports.comports()
        connected = []
        for element in comlist:
            connected.append(element.device)
        #print("Available COM ports: " + str(connected))

        ser = serial.Serial(port=serialPortName,timeout=3.0 )  # open serial port 3 sec read timout
        self.ser=ser        
        self.obMaskList={}
    
    
    def readevent(alpide,chipid):
        words=[]
        while True:
            lo=alpide.read_reg(chipid,0x0012)
            hi=alpide.read_reg(chipid,0x0013)
            word=(hi<<16|lo)&0xFFFFFF
            words.append(word)
            if (word>>16)&0xF0==0xB0: break
            if (word>>16)&0xF0==0xE0: break
            if word==0xFFFFFF: break
        return words

    # Function decodeevent()
    # 
    #  param words= 24bits unsigned ints (Pixel data)
    #  param decode - Sellect pixel-info to decode ( only ment for debuging ) 
    #   decode=0 - Dont decode any pixels :)
    #   decode=1 - Decode only long-data
    #   decode=2 - Decode ony  short-data
    #   decode=3   Decode long- & short-data
    def decodeevent(this,words,decode=3):
        #assert len(words)>0
        if(len(words)<0) :
            return []
        reg=None
        hits=[]
        if   words[0]&0xF000FF==0xE000FF: # chip empty
            pass
        elif words[0]&0xF000FF==0xA000FF: # chip header
            for word in words[1:-1]:
                if   word&0xC00000==0x000000: # data long
                    #print("Pix fmt long 0x%X"%word)
                    if(decode & 1) :
                        assert reg is not None
                        addr=reg<<14|word>>8&0x3FFF
                        hits.append(addr)
                        hm=word&0xFF
                        while hm:
                            addr+=1
                            if hm&1: hits.append(addr)
                            hm>>=1
                elif word&0xC000FF==0x4000FF: # data short                
                    #print("Pix fmt short 0x%X"%word)
                    if(decode&2):
                        assert reg is not None
                        hits.append(reg<<14|word>>8&0x3FFF)
                elif word&0xE0FFFF==0xC0FFFF: # region header
                    reg=word>>16&0x1F
                    #print("Region ID %06X  Region-Value %d"% (word,reg))
                else: raise ValueError('bad word: %06X'%word)
            if words[-1]&0xF000FF==0xB000FF: # chip trailer
                pass
            else: print('bad last word: %06X'%words[-1])#raise ValueError('bad last word: %06X'%words[-1])
        else: raise ValueError('bad first word: %06X'%words[0])

        xy=[(d>>9&0x3FE|(d^d>>1)&0x1,d>>1&0x1FF) for d in hits]
        return xy

#     def trgrdo(this,alpide):
#         alpide.global_cmd(0xD2) # GRST
#         alpide.global_cmd(0xE4) # PRST
#         alpide.write_reg(0x0F,0x0010,0x007F) # disable manchester, initial token
#         alpide.write_reg(0x0F,0x0004,0x0000) # disable BUSY monitoring
#         alpide.write_reg(0x0F,0x0001,0x020D) # readout via CMU
#         alpide.write_reg(0x0F,0x0005,60000) # strobe length
#         alpide.write_reg(0x0F,0x0602,147) # VRESETD
#         for i in range(1000):
#             alpide.global_cmd(0x55) # TRIGGER
#             #for chipid in [0x78,0x79,0x7A,0x7B,0x7C,0x7D,0x7E]:
#             for chipid in [0x10]:
#                 hits=decodeevent(readevent(alpide,chipid))
#                 for x,y in hits:
#                     print(chipid,x,y)

    # Get list from memeory struct
    #  Debug Funn :)
    def getPixelsFromMem(this):
        # input Data Stream stream of 24 bits to reduce Tx time
        # 0xA093FF  - header     ( start pixel data)
        # 0xC0FFFF  - Region-id  ( X pos Ofset )
        # 0x42BDFF  - data short ( px fmt single   pixel  )
        # 0x030128  - data long  ( px fmt multiple pixels )    
        # 0xB0FFFF  - trailer    ( end of pixel data)
                     # Header             Region-id           data - short     data - long       trailer
                     #0xA093FF            #0xC0FFF            0x42BDFF         #0x030128         0xB0FFFF
        data = bytes([0xA0, 0x93,0xFF,   0xC0, 0xFF,0xFF , 0x42,0xBD, 0xFF,  0x03,0x01,0x28,    0xB0,0xFF,0xFF ])

        #Send data as 24bits to reduce time.. (PC-faster than ucontroller :)
        lst=[]
        # Splitt in 24 bits
        for i in range(0,len(data),3) :
            lst.append(int.from_bytes(data[i:i+3], byteorder='big', signed=False))        

        return lst

    #   Return data JSON Formated information
    def getQueryGetPixelFrameData(this,chipID):
        sId = ("%s" % chipID).encode()
        return b'{"getPixelFrameData": [{"chipID":' +sId+ b'}]} \r\n'    

    #   Return data JSON Formated information
    #      example output: {"readRegister": { "chipID": 112, "addr": 609   } }
    def getQueryReadRegister(this,chipID,addr):
        sId   = ("%s" % chipID).encode()
        sAddr = ("%s" % addr).encode()
        return   b'{"readRegister": {"chipID":'+sId +b',"addr":'+sAddr+b' } } \r\n' ;

    def sendQueryReadRegister(this,chipID,addr):
        this.ser.write(this.getQueryReadRegister(chipID,addr))
        
        #return '{ "alpideRegister": [ { "addr": 609 , " value": 35}  ] }'
        return  this.ser.readline() 

    #   Return data JSON Formated information
    #      example output:  {"writeRegister": {     "chipID": 112,   "addr": 1545  ,"data" : 100  } }
    def getQueryWriteRegister(this,chipID,addr,data):
        sId   = ("%s" % chipID).encode()
        sAddr = ("%s" % addr).encode()
        sData = ("%s" % data).encode()
        
        return   b'{"writeRegister": {"chipID":'+sId +b',"addr":'+sAddr+b',"data":'+sData +b'} } \r\n' ;

    def sendQueryWriteRegister(this,chipID,addr,data):
        this.ser.write(this.getQueryWriteRegister(chipID,addr,data))
        ok=this.ser.readline()
       

    def sendTrigger(this):
        this.ser.write(b' {"sendTrigger": "True" }\r\n')
        ok=this.ser.readline()
     
    def sendReset(this):
        this.ser.write(b' {"sendRest": "True" }\r\n')
        ok=this.ser.readline()


    def sendMaskPixels(this,chipID,lstPixels) :     
        #lst=[(39, 490), (70, 258), (75, 254), (512, 439), (549, 64), (817, 503), (1007, 458)]
        #str='{"maskPixels": ['
        #for x,y in lst :
        #    print(x,y)
        #    
        strMask= b'{"maskPixels": [{"chipID": 112, "x": 1 ,"y" : 350  },{"chipID": 112, "x": 1 ,"y" : 384  },{"chipID": 112, "x": 1 ,"y" : 386  },{"chipID": 112, "x": 0 ,"y" : 387  }]    } \r\n'
        this.ser.write(strMask)
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

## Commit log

2022-10-19 Arduino IDEv2.0 RPI PICO Serial Interface for the ITS OB telescope
2022-10-19 RAW FIFO Data Containing ALPIDE Hits
    [data2.csv, trgData.csv]
2022-10-19 Library RPI Pico Serial <--> ALPIDE OB Module
2022-10-19 Example usage of Library RPI Pico Serial <--> ALPIDE OB Module
2022-10-19 RPI Pico interface
    [Pico_Interface-B_Cu.gbr, Pico_Interface-B_Mask.gbr, Pico_Interface-B_Paste.gbr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]
2022-10-20 Added 4 PMOD / IDC Connectors
    [Pico_Interface.kicad_pcb, Pico_Interface.kicad_sch]
2022-10-20 DRC Warning fix
    [Pico_Interface.kicad_pcb]
2022-10-20 Started change of layout
    [Pico_Interface.kicad_pcb, Pico_Interface.kicad_sch]
2022-10-20 Added Trigger/Bussy and 3.3V LDO
    [Pico_Interface.kicad_pcb, Pico_Interface.kicad_sch]
2022-10-21 Added new Col to BOM (Farnell Order URL)
    [Pico_Interface.kicad_sch]
2022-10-21 BOM Update
    [Pico_Interface.kicad_sch]
2022-10-21 Added Title Block
    [Pico_Interface.kicad_sch]
2022-10-21 Kicad PCB Routed and ready for Production
    [Pico_Interface.csv, Pico_Interface.kicad_pcb]
2022-10-21 Fix Silk text
    [Pico_Interface.kicad_pcb]
2022-10-22 Setting eanable export of all components into .setp (Pio Pico is only in wrl..)
2022-10-24 Added 3d Models and RPI Pico symbol & foothprint
    [Pico_Interface.kicad_pcb]
2022-10-27 started on func filterOutDeadPix
2022-10-27 Added Simple Backplane
    [AlpideReaderCover.FCStd, Pico_Interface1-Body.stl]
2022-10-27 View Update
    [AlpideReaderCover.FCStd]
2022-10-28 Add board width bumper image
2022-10-28 Added USB Pocket
    [AlpideReaderCover.FCStd, Pico_Interface1-Body.stl]
2022-10-31 Arduino CLI install Instructions
2022-11-01 BugFix Send reset and not trigger on reset command
    [alpideInterface.ino]
2022-11-02 Fix Cover fitting
    [AlpideReaderCover.FCStd]
